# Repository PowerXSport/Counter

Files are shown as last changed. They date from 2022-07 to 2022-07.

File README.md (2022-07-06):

# Counter
Source code and 3d models for the PowerX rep counter

# Wiring
| Component | GX-16 |  RPi |
|---|:-----:|:----:|
| Click Button Center | 1 |  16  |
| Click Button** | 8 | 1  |
| Plus  Button*** | 2 |  13  |
| Minus Button*** | 3 |  15  |
| +/- Button Center | 8 |  1 |
| Vib. Motor Signal | 4 |  10  |
| Vib. Motor Positive | 8 |  1 |
| Vib. Motor Negative | 7 |  6 |
| Buzzer Positive |  N/A  |  12  |
| Buzzer Negative |  N/A  |  6 |

**Wire to one side of switch (L/R pole)

***The rocker +/- switch activates the opposite pole

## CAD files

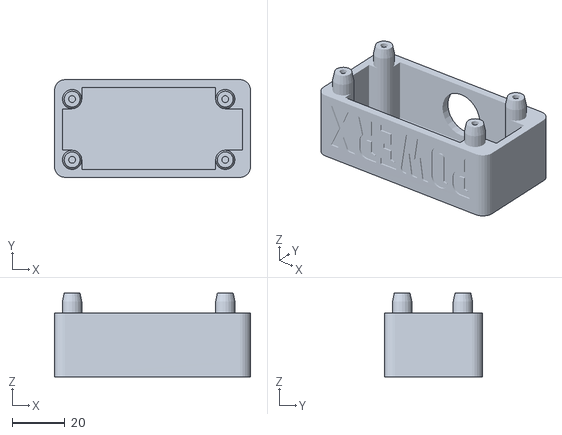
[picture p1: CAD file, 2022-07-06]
3d/pizero-case-screws-top.stl
74.2 x 37.1 x 31.7

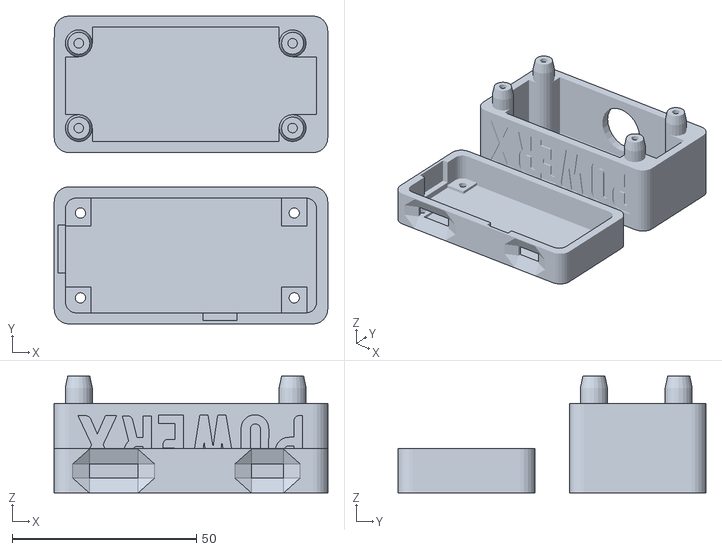
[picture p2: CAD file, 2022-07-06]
3d/pizero-case-screws.stl
74.2 x 83.5 x 31.7

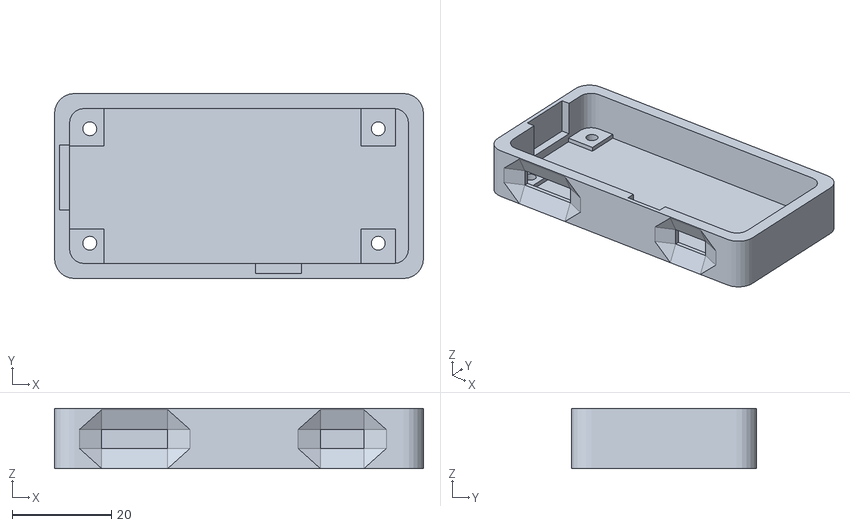
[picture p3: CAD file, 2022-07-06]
3d/pizero-case-screws-bottom.stl
74.2 x 37.2 x 12.1

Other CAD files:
3d/button.skp
3d/pizero-case-screws.skp

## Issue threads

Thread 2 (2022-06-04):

Change reset sequence

cmilam87, 2022-06-04:
When the timer ends, the next click clears the counter.

Lets change this so it takes three (3) clicks to reset the counter

cmilam87, 2022-06-04:
Could we try pressing the minus button and clicking once as a reset sequence?

cmilam87, 2022-06-04:
Let's do:
* Hold minus button
* Double click on counter button

For the reset sequence

Closed 2022-06-05.

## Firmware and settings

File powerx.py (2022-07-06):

import kivy
import RPi.GPIO as GPIO
import time

from kivy.app import App
from kivy.uix.gridlayout import GridLayout
from kivy.properties import StringProperty
from kivy.clock import Clock

plusButtonPinNum = 13
minusButtonPinNum = 15
buttonPinNum = 16
buzzerPinNum = 12
hapticMotorPinNum = 10

totalSeconds = 60
totalMilliseconds = totalSeconds * 1000
maxReps = 0
minWeight = 15
maxWeight = 700

def gpio_init():
	GPIO.setmode(GPIO.BOARD)
	
	# INS
	GPIO.setup(buttonPinNum, GPIO.IN, pull_up_down=GPIO.PUD_DOWN)
	GPIO.setup(plusButtonPinNum, GPIO.IN, pull_up_down=GPIO.PUD_DOWN)
	GPIO.setup(minusButtonPinNum, GPIO.IN, pull_up_down=GPIO.PUD_DOWN)

	# OUTS
	GPIO.setup(buzzerPinNum, GPIO.OUT)
	GPIO.setup(hapticMotorPinNum, GPIO.OUT)


def formatTime(time): #time is in milliseconds
	minutes = int((time / (1000 * 60)) % 60)
	seconds = int((time / 1000) % 60)
	tenths = int((time % 1000) / 100)
	
	if time <= 60000:
		seconds = int(time / 1000)
		return "{0:02d}.{1}".format(seconds, tenths)
	else:
		return "{0}:{1:02d}".format(minutes, seconds)

class PowerXCounter(GridLayout):
	currentReps = 0
	totalTimeMilliseconds = totalMilliseconds
	prevBtnInput = 0

	#PROPERTIES
	timeRemaining = StringProperty(formatTime(totalTimeMilliseconds))
	counter = StringProperty("0")
	totalTons = StringProperty("0")
	weight = StringProperty(str(minWeight))

	def __init__(self, **kwargs):
		super(PowerXCounter, self).__init__(**kwargs)
		self.reset()
		Clock.schedule_interval(self.checkInput, 0.15)

	def reset(self):
		#GPIO / CLOCK RESET
		Clock.unschedule(self.timer)
		Clock.schedule_once(self.buzzeroff)

		#RESETS VARS	
		self.currentReps = 0
		self.totalTimeMilliseconds = totalMilliseconds
		self.prevBtnInput = GPIO.input(buttonPinNum)
		self.countdowninprogress = False
		self.countdownnum = 3
		self.buzzerlength = 1
		self.hapticMotorLength = 0.5
		self.timerRunning = False

		#RESET LABELS
		self.counter = "0"
		self.timeRemaining = formatTime(totalMilliseconds)
		self.weight = str(minWeight)
		self.totalTons = "0"

		Clock.schedule_once(self.hapticMotor)

	def checkInput(self, dt):
		# Keep track of button states
		btnInput = GPIO.input(buttonPinNum)
		plusBtn = GPIO.input(plusButtonPinNum)
		minusBtn = GPIO.input(minusButtonPinNum)

		btnClicked = self.prevBtnInput != btnInput
		if btnClicked:
			# always keep track of the button state
			self.prevBtnInput = btnInput

			if minusBtn:
				self.reset()
			else:
				self.click()

		elif self.currentReps == 0:
			w = int(self.weight)
			if plusBtn and w < maxWeight:
				w += 5
			if minusBtn and w > minWeight:
				w -= 5
			self.weight = str(w)


	def countdown(self, dt):
		if self.countdownnum > 0:
			self.hapticMotorLength = 0.2
			Clock.schedule_once(self.hapticMotor)
			self.countdowninprogress = True
			self.totalTons = str(self.countdownnum)
			self.countdownnum -= 1
		else:
			self.totalTons = "GO!"
			self.countdowninprogress = False
			self.hapticMotorLength = 1
			Clock.schedule_once(self.hapticMotor)
			Clock.unschedule(self.countdown)
			Clock.schedule_once(self.buzzer)
			Clock.schedule_once(self.setnum, 0.3)
			Clock.schedule_interval(self.timer, 0.1)

	def setnum(self, dt):
		self.totalTons = "0"

	def settons(self):
		self.totalTons = str(self.currentReps * int(self.weight))

	def buzzeroff(self, dt):
		GPIO.output(buzzerPinNum, False)

	def buzzer(self, dt):
		GPIO.output(buzzerPinNum, True)			
		Clock.schedule_once(self.buzzeroff, self.buzzerlength)

	def hapticMotorOff(self, dt):
		GPIO.output(hapticMotorPinNum, False)

	def hapticMotor(self, dt):
		GPIO.output(hapticMotorPinNum, True)
		Clock.schedule_once(self.hapticMotorOff, self.hapticMotorLength)

	def click(self):
		if self.countdowninprogress:
			return

		if self.currentReps == 0:
			Clock.schedule_interval(self.countdown, 0.5)
		elif self.currentReps < maxReps or maxReps == 0:
			self.counter = str(self.currentReps)
			self.settons()
		elif self.currentReps == maxReps:
			self.counter = str(maxReps)
			self.settons()
			Clock.unschedule(self.timer)

		self.currentReps += 1

	def timer(self, dt):
		self.totalTimeMilliseconds -= 100
		self.timerRunning = True
		self.timeRemaining = formatTime(self.totalTimeMilliseconds)
		if self.totalTimeMilliseconds == 0:
			Clock.unschedule(self.timer)
			self.buzzerlength = 3
			self.timerRunning = False
			Clock.schedule_once(self.buzzer)
			self.hapticMotorLength = 1
			Clock.schedule_once(self.hapticMotor)
		elif self.totalTimeMilliseconds in [3000, 2000, 1000]:
			self.hapticMotorLength = 0.5
			Clock.schedule_once(self.hapticMotor)

class PowerXApp(App):
	def build(self):
		gpio_init()
		return PowerXCounter()
	
if __name__ == "__main__":
	PowerXApp().run()

GPIO.output(buzzerPinNum, False)
GPIO.cleanup()

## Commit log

2020-03-06 added 3d models
    [button.skp, pizero-case-screws.skp]
2020-03-06 updated 3d model and gitignore
    [pizero-case-screws.skp]
2022-07-06 Added support for vibration motor. Added STLs for case.
    [pizero-case-screws-bottom.stl, pizero-case-screws-top.stl, pizero-case-screws.stl]
